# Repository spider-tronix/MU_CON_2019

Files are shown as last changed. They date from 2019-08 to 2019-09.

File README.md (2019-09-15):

# Aragog
Ever wanted to build a bot that moves around by your command? Nah… not very interesting. Throw
in a few legs and make a crawling hexapod, how cool would that be? Maybe make it wireless -
controllable with your own phone. Now we’re talking!

This year Spider, the R&D club of NITT, presents to you μCon'19, workshop on ‘Aragog’, a Bio-
Inspired Spider Bot. Discover the world of microcontrollers, wireless communication, app-
development, and 3D kinematics. Make your own creepy-crawler with custom-built acrylic frames!

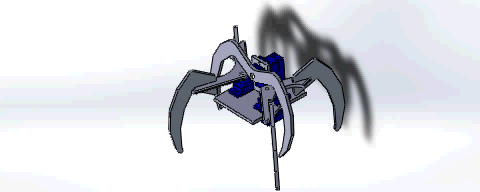
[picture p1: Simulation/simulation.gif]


# Components Used
* Arduino Nano
* Servos (3)
* Bluetooth Module (HC-05)
* 9V Batteries (2)
* Laser Cut Acrylic Frame
* Screws
* Custom PCB
* Assorted Jumpers
* Misc Hand Tools

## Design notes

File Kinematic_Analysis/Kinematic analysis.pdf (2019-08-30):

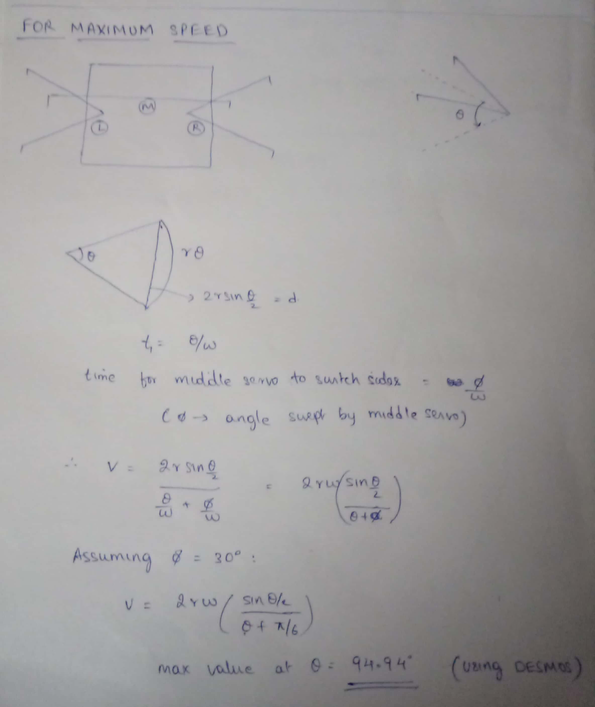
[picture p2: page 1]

Scanned by CamScanner

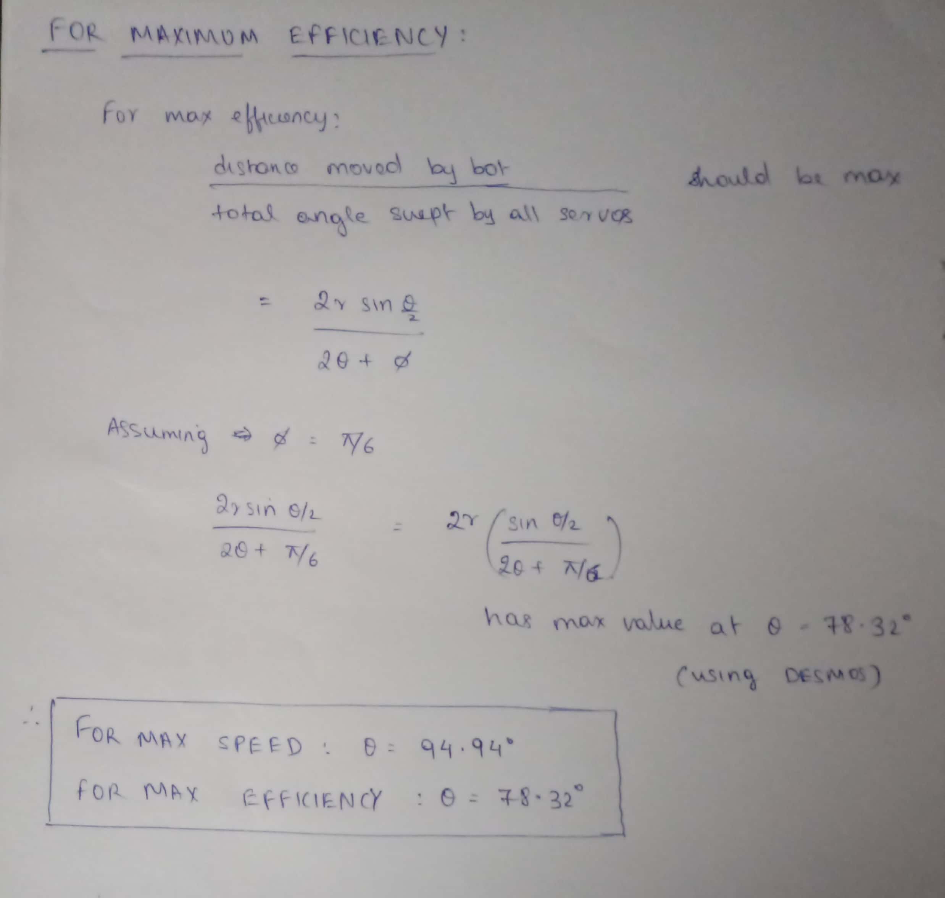
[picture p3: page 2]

Scanned by CamScanner

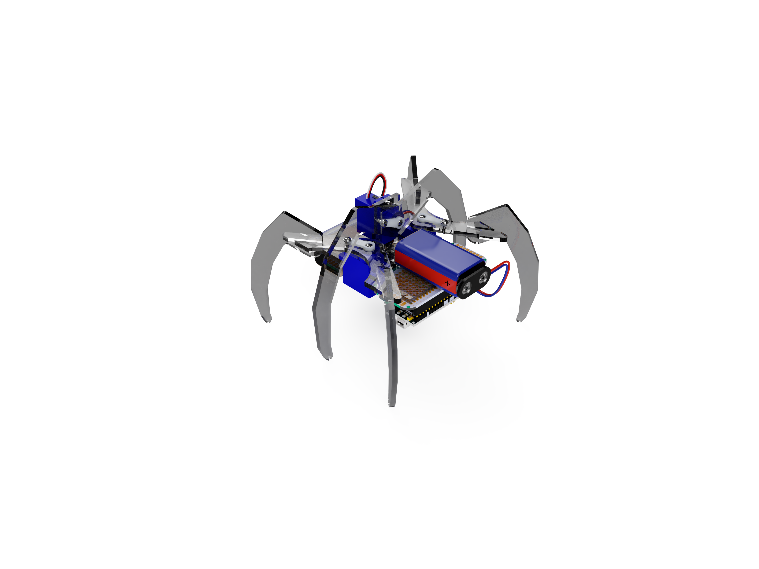
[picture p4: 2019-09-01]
Design/render/isometric_2.PNG

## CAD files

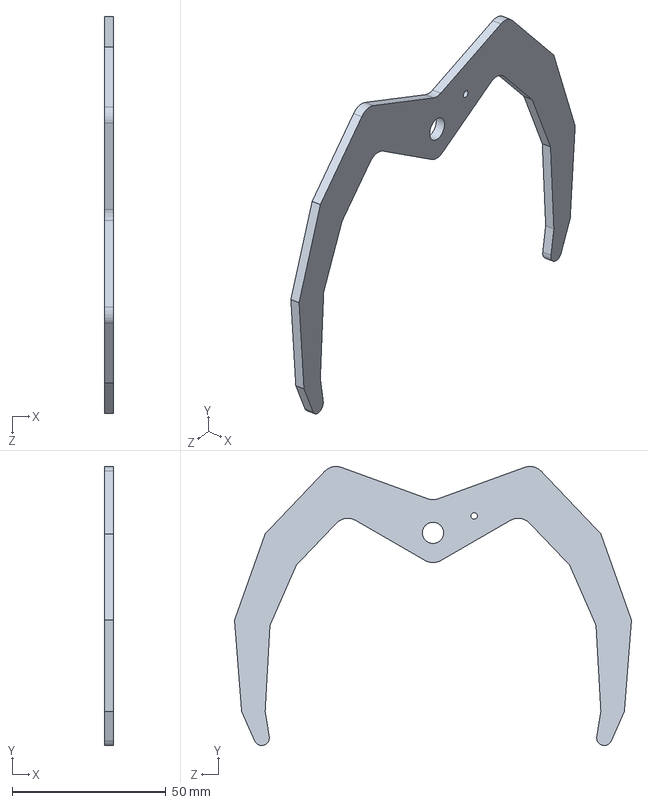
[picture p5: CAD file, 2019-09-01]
Design/assembly-files/m-legs.SLDPRT
3.00 x 90.6 x 128.9 mm

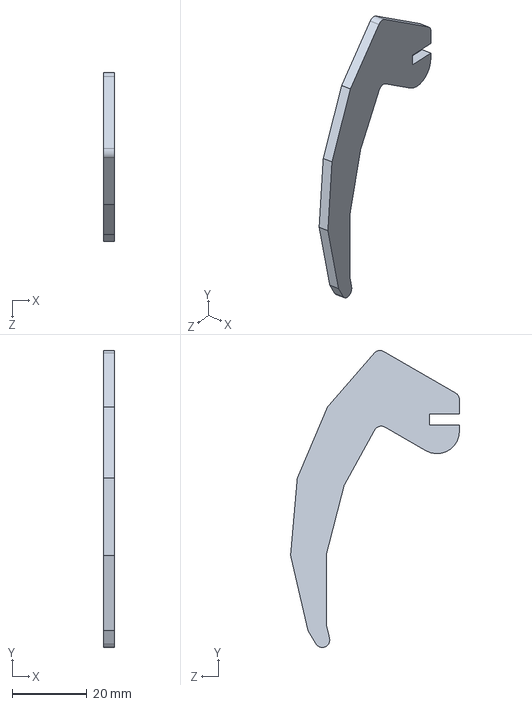
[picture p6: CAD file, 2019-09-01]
Design/assembly-files/legs.SLDPRT
3.00 x 79.3 x 45.1 mm

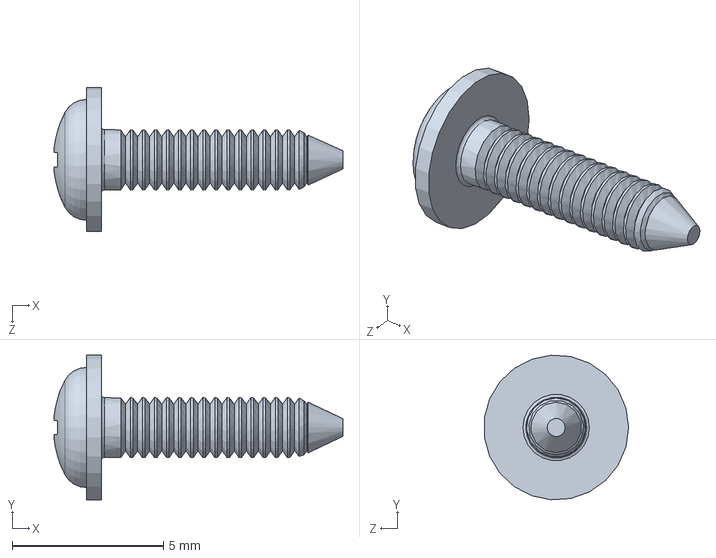
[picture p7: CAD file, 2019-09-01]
Design/assembly-files/SG90 - Micro Servo 9g - Tower Pro.5.SLDPRT
9.57 x 4.79 x 4.78 mm

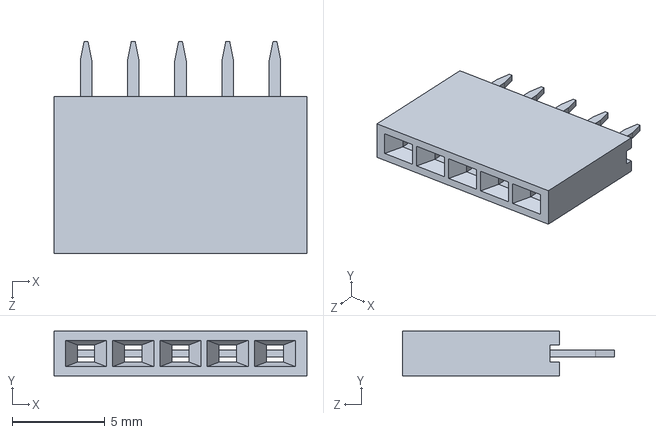
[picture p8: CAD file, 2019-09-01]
Design/assembly-files/Header_Female_1x5.SLDPRT
13.6 x 2.42 x 11.4 mm

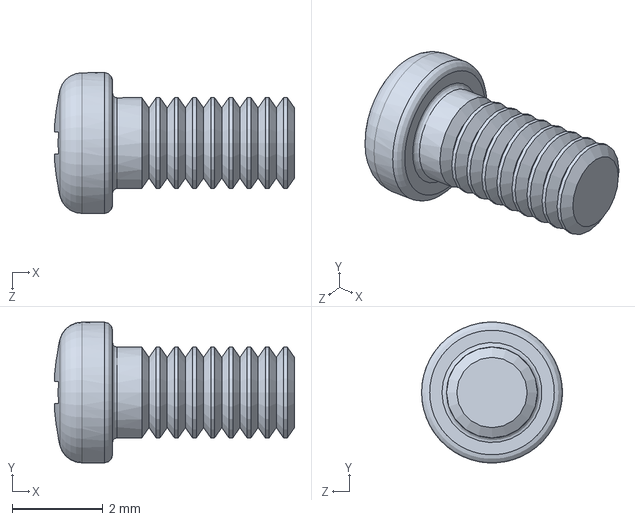
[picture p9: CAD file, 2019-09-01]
Design/assembly-files/SG90 - Micro Servo 9g - Tower Pro.6.SLDPRT
5.28 x 3.10 x 3.10 mm

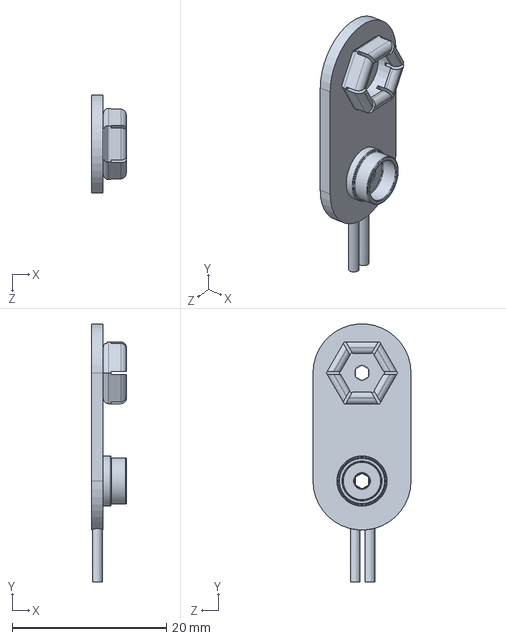
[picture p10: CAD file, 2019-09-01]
Design/assembly-files/9v battery cell button.SLDPRT
4.50 x 33.4 x 12.7 mm

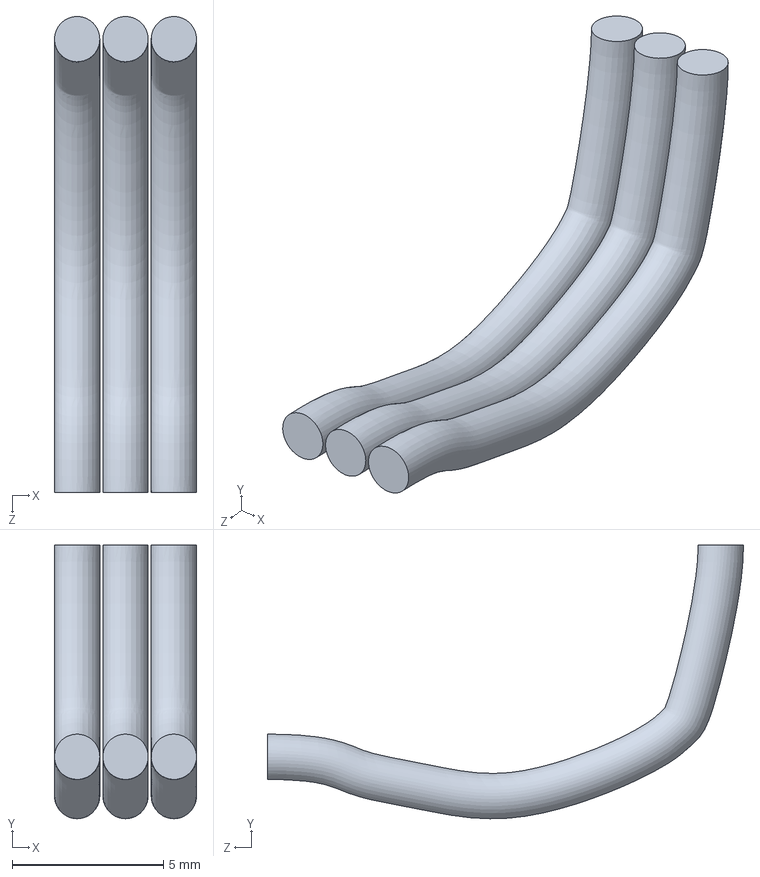
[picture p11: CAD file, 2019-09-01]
Design/assembly-files/lsw.SLDPRT
4.70 x 9.05 x 15.7 mm

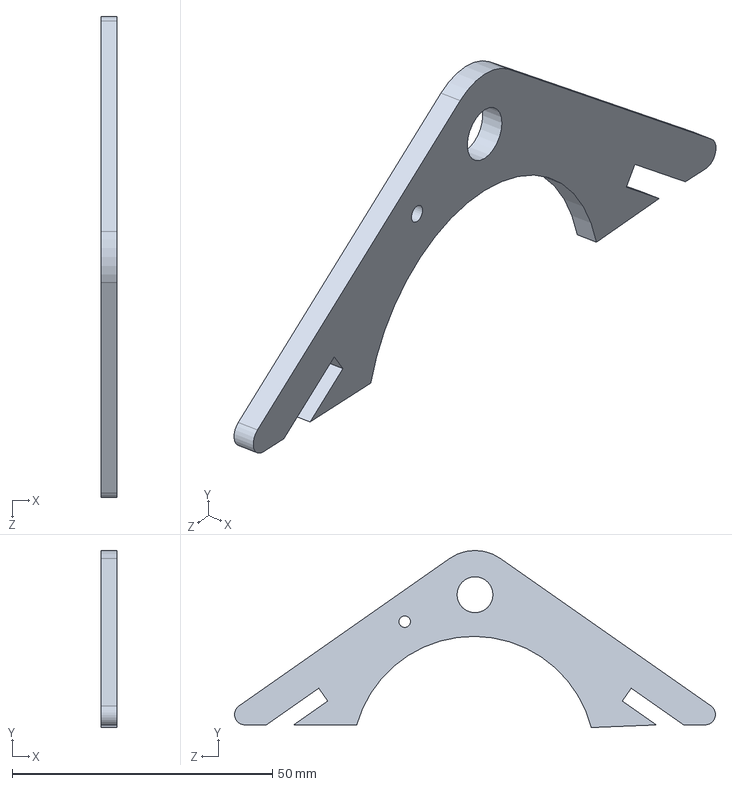
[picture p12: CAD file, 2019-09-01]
Design/assembly-files/leg-holder.SLDPRT
3.00 x 34.0 x 92.4 mm

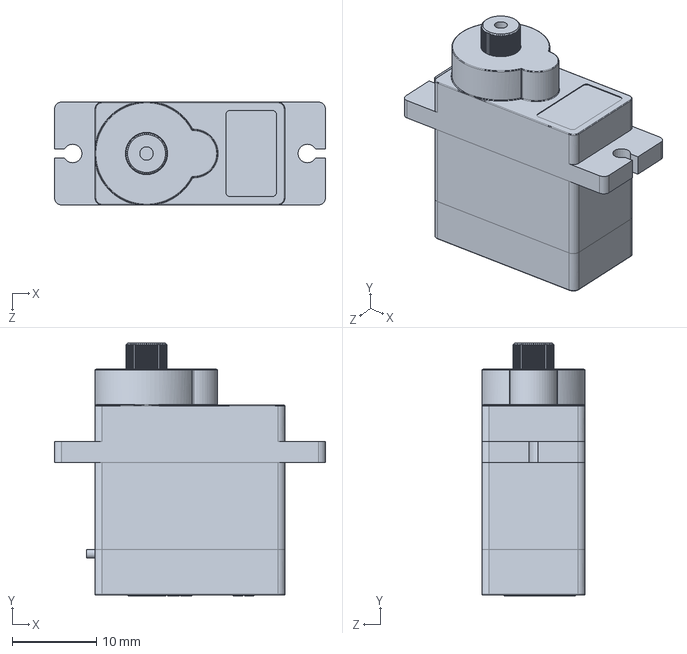
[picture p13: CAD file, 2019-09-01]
Design/assembly-files/SG90 - Micro Servo 9g - Tower Pro.1.SLDPRT
32.1 x 30.0 x 12.2 mm

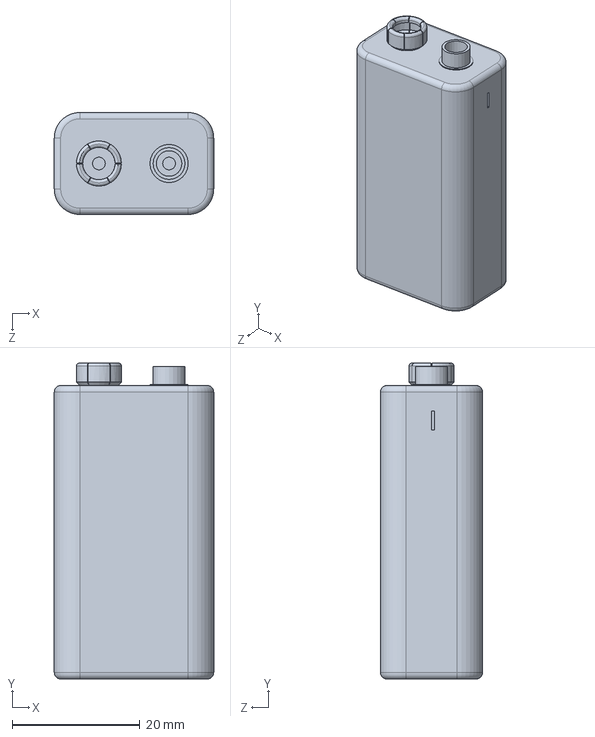
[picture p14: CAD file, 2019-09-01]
Design/assembly-files/9V-2.SLDPRT
25.0 x 49.5 x 16.0 mm

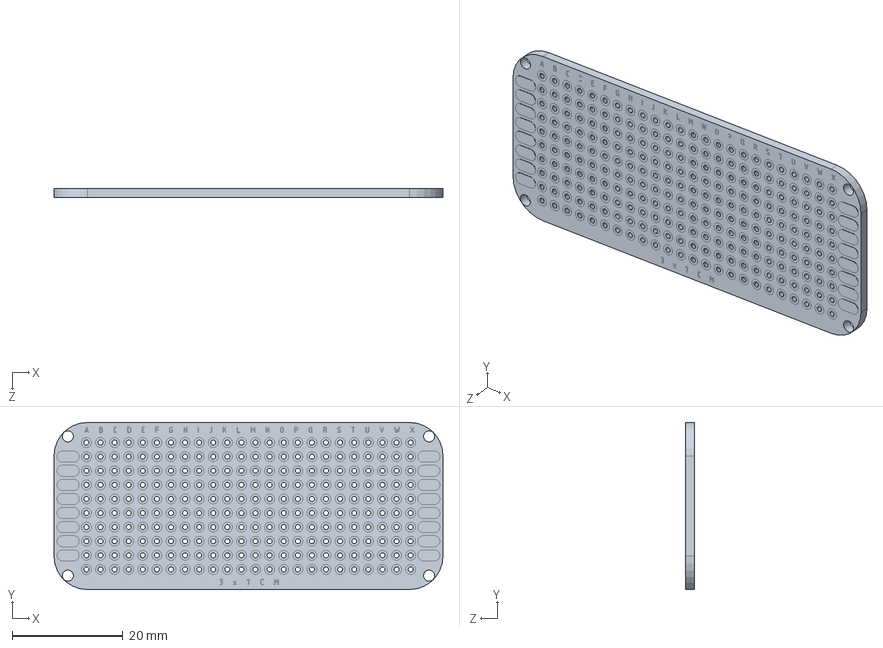
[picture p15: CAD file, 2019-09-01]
Design/assembly-files/pcb.SLDPRT
70.1 x 30.1 x 1.65 mm

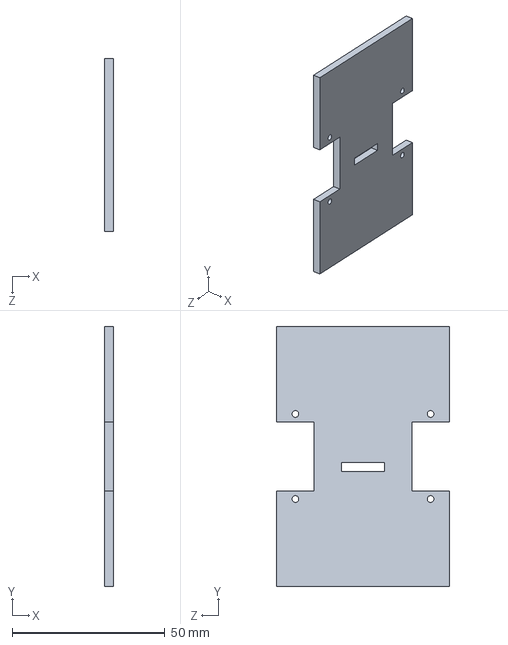
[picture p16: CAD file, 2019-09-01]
Design/assembly-files/spider-square-base.SLDPRT
3.00 x 85.0 x 56.4 mm

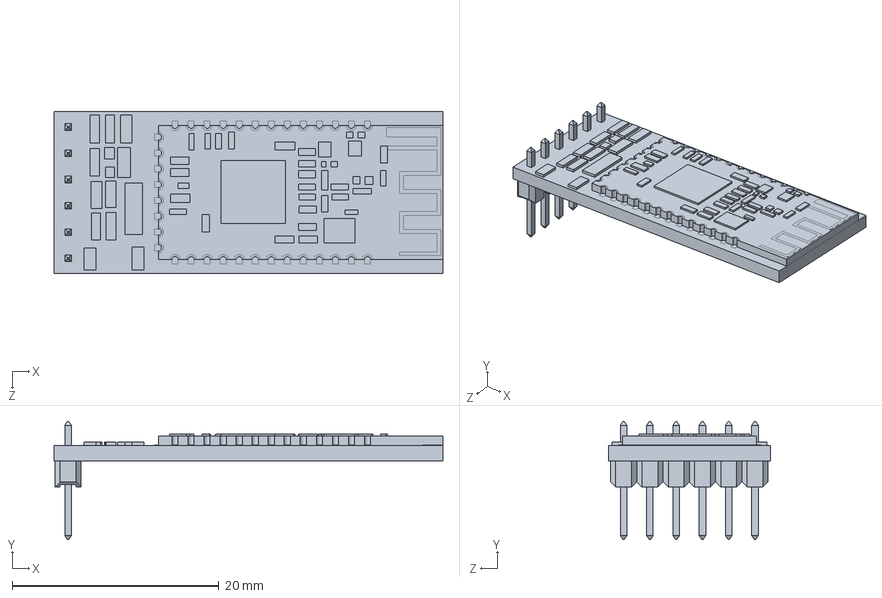
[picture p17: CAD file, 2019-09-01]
Design/assembly-files/HC-SERIES.SLDPRT
37.6 x 11.4 x 15.7 mm

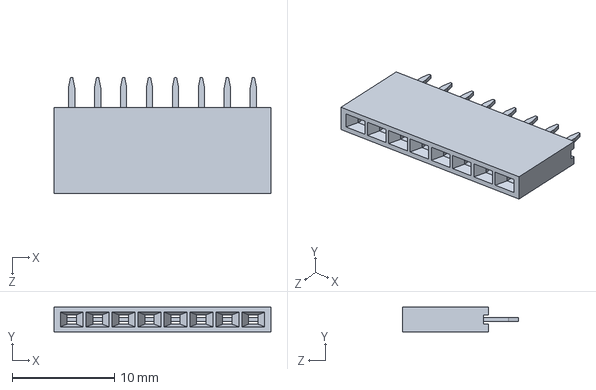
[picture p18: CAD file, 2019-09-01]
Design/assembly-files/Header_Female_1x8.SLDPRT
21.2 x 2.42 x 11.4 mm

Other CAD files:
Design/assembly-files/Header_Female_1x6.SLDPRT
Design/assembly-files/SG90 - Micro Servo 9g - Tower Pro.2.SLDPRT
Design/assembly-files/Header_Female_1x2.SLDPRT
Design/assembly-files/rsw.SLDPRT
Design/assembly-files/M2 x 0.4mm Thread 12mm LONG SOCKET HEAD CAP SCREW.SLDPRT
Design/assembly-files/M2 x 0.4mm Thread HEX NUT.SLDPRT
Design/assembly-files/mid-servo-wire.SLDPRT
Design/assembly-files/support-key.SLDPRT
Design/assembly-files/support.SLDPRT

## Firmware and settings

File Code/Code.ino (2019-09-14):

/*
    Filename: Code.ino
    Author: The real Spider Tronix 2019
    Purpose: First years' uCON  workshop (2019)
 */

//REQUIRED HEADERS
#include <avr/interrupt.h>
#include <avr/io.h>

#define OCR1_2ms 3999
#define OCR1_1ms 1800

// Servo Constants
#define left_servo_bottom_angle 10
#define left_servo_top_angle 80
#define right_servo_bottom_angle 70
#define right_servo_top_angle 10
#define middle_servo_left_angle 0
#define middle_servo_right_angle 30

//CONSTANS FOR BOT DIRECTIONS
#define DIR_NONE 0
#define DIR_FRONT 1
#define DIR_LEFT 2
#define DIR_RIGHT 3

// Pins For Servo
#define MIDDLE_SERVO 6
#define LEFT_SERVO 9
#define RIGHT_SERVO 10

volatile float time0 = 0;
float duty_time; ///(min - 1ms, max -2ms)

void serial_init(unsigned long baud = 9600)
{
    if (baud == 9600)
    {
        UCSR0A = 0X00;
        UCSR0B = (1 << RXEN0) | (1 << TXEN0);
        UCSR0C = (1 << UCSZ01) | (1 << UCSZ00);
        UBRR0 = 103; //Set baud rate to 9600
    }
}
void serial_print(String data)
{
    for (int i = 0; data[i] != '\0'; i++)
    {
        while (!(UCSR0A & (1 << UDRE0)))
            ;
        UDR0 = data[i];
    }
}
char serial_read()
{
    if ((UCSR0A & (1 << RXC0)))
    {
        char temp = UDR0;
        if (temp != '\n' && temp != '\r')
            return temp;
    }

    return 0;
}

ISR(TIMER0_OVF_vect)
{
    time0 += 0.128; // Calculate time (min - 0ms, max - 2ms)
    if (time0 >= 20)
    {
        PORTD |= 1 << 6; // At 20 ms reset time0 to 0 and pull the pin back high
        time0 = 0;
    }
    else if (time0 >= duty_time)
    {
        PORTD = 0; // At time0 = duty_time make pin low for getting desired duty cycle
    }
}

void servo_begin(int pin)
{
    if (pin == 9)
    {
        /*Set pre-scaler of 8 with Fast PWM (Mode 14 i.e TOP value as ICR1)  non-inverting mode */
        DDRB |= 1 << PINB1;
        TCCR1A |= (1 << WGM11) | (1 << COM1A1);
        TCCR1B |= (1 << WGM12) | (1 << WGM13) | (1 << CS11);
        ICR1 = 39999; // Set pwm period as 20ms
    }
    if (pin == 6)
    {
        DDRD |= 1 << 6;
    }
    if (pin == 10)
    {
        /*Set pre-scaler of 8 with Fast PWM (Mode 14 i.e TOP value as ICR1)  non-inverting mode */
        DDRB |= 1 << PINB2;
        TCCR1A |= (1 << WGM11) | (1 << COM1B1);
        TCCR1B |= (1 << WGM12) | (1 << WGM13) | (1 << CS11);
        ICR1 = 39999; // Set pwm period as 20ms
    }
}

// Write the servo's angle
void servo_write(float angle, int pin)
{
    if (pin == 9)
        OCR1A = map(angle, 0, 180, OCR1_1ms, OCR1_2ms); // Map angle to OCR1 value
    if (pin == 6)
    {
        duty_time = 1 + (float)(angle / 180);
        TCCR0B = 1 << CS01; //8 bit prescale gives 0.128ms per overflow
    }
    if (pin == 10)
        OCR1B = map(angle, 0, 180, OCR1_1ms, OCR1_2ms); // Map angle to OCR1B
}

/*
 * timer0 compare match a
 */
volatile int timer0_counter = 0;

/*
overflows counts number of overflows of Timer2
*/
volatile int overflows = 0;

ISR(TIMER2_OVF_vect)
{
    ++overflows;
}

/*
Using timer 2 to cause a delay of a given time
*/
void delayinms(int time_)
{
    overflows = 0;

    TCCR2B = 1 << CS21 | 1 << CS20;    //32 bit prescale gives 0.512ms per overflow
    while (overflows * 0.512 <= time_) // wait till count of overflows equals time_
        ;
    TCCR2B = 0; // turn timer off after use
}

// Enable Overflow interrupt
void timer_init()
{
    TIMSK2 = 1 << TOIE2;
    TIMSK0 = 1 << TOIE0;
}

// Initialize position of legs for forward motion
void move_forward_init()
{
    servo_write(middle_servo_right_angle, MIDDLE_SERVO);
    servo_write(left_servo_bottom_angle, LEFT_SERVO);
    servo_write(right_servo_top_angle, RIGHT_SERVO);
    delayinms(500);
}
// Complete one full cycle of forward motion gait
void move_forward()
{
    servo_write(middle_servo_left_angle, MIDDLE_SERVO);
    delayinms(200);
    servo_write(left_servo_top_angle, LEFT_SERVO);
    servo_write(right_servo_bottom_angle, RIGHT_SERVO);
    delayinms(500);

    servo_write(middle_servo_right_angle, MIDDLE_SERVO);
    delayinms(200);
    servo_write(left_servo_bottom_angle, LEFT_SERVO);
    servo_write(right_servo_top_angle, RIGHT_SERVO);
    delayinms(500);
}
// Initialize position of legs for left rotation
void turn_left_init()
{
    servo_write(middle_servo_right_angle, MIDDLE_SERVO);
    servo_write(left_servo_top_angle, LEFT_SERVO);
    servo_write(right_servo_top_angle, RIGHT_SERVO);
    delayinms(500);
}
// Complete one full cycle of left rotation gait
void turn_left()
{
    servo_write(middle_servo_left_angle, MIDDLE_SERVO);
    servo_write(left_servo_bottom_angle, LEFT_SERVO);
    servo_write(right_servo_bottom_angle, RIGHT_SERVO);
    delayinms(500);
    servo_write(middle_servo_right_angle, MIDDLE_SERVO);
    servo_write(left_servo_top_angle, LEFT_SERVO);
    servo_write(right_servo_top_angle, RIGHT_SERVO);
    delayinms(500);
}
// Initialize position of legs for right rotation
void turn_right_init()
{
    servo_write(middle_servo_left_angle, MIDDLE_SERVO);
    servo_write(left_servo_top_angle, LEFT_SERVO);
    servo_write(right_servo_top_angle, RIGHT_SERVO);
    delayinms(500);
}
// Complete one full cycle of right rotation gait
void turn_right()
{
    servo_write(middle_servo_right_angle, MIDDLE_SERVO);
    servo_write(left_servo_bottom_angle, LEFT_SERVO);
    servo_write(right_servo_bottom_angle, RIGHT_SERVO);
    delayinms(500);
    servo_write(middle_servo_left_angle, MIDDLE_SERVO);
    servo_write(left_servo_top_angle, LEFT_SERVO);
    servo_write(right_servo_top_angle, RIGHT_SERVO);
    delayinms(500);
}

/*
        Use: Initialize movement in a particular direction 
        Note: To be called only once when there is a change in the direction of movement
     */
void move_init(int direction)
{
    switch (direction)
    {
    case DIR_FRONT:
        move_forward_init();
        break;
    case DIR_LEFT:
        turn_left_init();
        break;
    case DIR_RIGHT:
        turn_right_init();
        break;
    }
}

/*
Use: To be looped infinitely to move the bot
*/
void move(int direction)
{
    switch (direction)
    {
    case DIR_FRONT:
        move_forward();
        break;
    case DIR_LEFT:
        turn_left();
        break;
    case DIR_RIGHT:
        turn_right();
        break;
    }
}

int main()
{
    timer_init();
    sei(); //Enable global interrupts
    serial_init(9600);
    servo_begin(LEFT_SERVO);     
    servo_begin(MIDDLE_SERVO);    
    servo_begin(RIGHT_SERVO);               
    move_forward_init();
    delayinms(1000);

    int direction = DIR_NONE;

    while (1)
    {
        /* if (USART::bufferReady())
        {
            char temp[2];
            USART::readBuffer(temp); //the buffer is expected to receive '0', '1', '2', '3', etc..
            direction = temp[0] - '0';  //Convert ASCII to absolute value 
            spider_bot.move_init(direction);
            
        }
        USART::sendByte(direction + '0');*/
        char t = serial_read();
        if (t)
        {
            direction = t - '0';
            serial_print("change\n");
            move_init(direction);
        }
        move(direction);
    }
    return 0;
}

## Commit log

2019-08-22 Added servo control-incomplete
2019-08-24 modified servo control
2019-08-24 Further Updates to Servo Control
2019-08-24 test servo control: success!
2019-08-24 test servo at pin 6: fail
    [Code.ino]
2019-08-24 rectified timer0 control for servo at pin 6
2019-08-25 Modified timer0 operation to complete software type
2019-08-25 bot class error corrected
    [Code.ino]
2019-08-26 fix USART read, document
    [Code.ino]
2019-08-27 Add Design
    [Assem1.SLDASM, leg-holder.SLDPRT, legs.SLDPRT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]
2019-08-29 Added Kinematic Analysis
2019-08-31 Edited PCB design
    [ucon19-1.fzz]
2019-08-31 designs changed
    [Assem1.SLDASM, battery.SLDPRT, drawing-final.SLDDRW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]
2019-09-14 Convert Serial and Servos
2019-09-15 Big Spring Cleanup
